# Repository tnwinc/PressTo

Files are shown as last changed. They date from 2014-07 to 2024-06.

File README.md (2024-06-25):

NOTE:
=======
This repo is being archived because it was never used for more than a prototype. The code is obsolete and being retired.

PressTo
=======

Pronounced \'pres-tō\\. This repository contains details on how to make an Adruino powered switch box to select and launch an application. "Press To ..."

# Parts
* Arduino (Uno, Nano, etc., tested with the ATmega328 microcontroller)
* Capacitive Touch Wheel (http://www.dfrobot.com/index.php?route=product/product&product_id=463)
* Green Button (http://amzn.com/B0094GRZPE)
* Red Button (http://amzn.com/B0097A8PK6)
* Plastic Printer (for the housing)

# Hardware
Hopefully a schematic of our design will be provided, but it is not yet available...

## Microcontroller code
Look up the code in ArduinoSide/SelectorDevice/SelectorDevice.ino. The microcontroller code is hooked to A0 (for the Rotary analog input), D2 (green button), D3 (red button), and power (5V) and ground are run as needed to all three components. 

On a button press, the appropriate signal is sent, namely BUTTON_GREEN or BUTTON_RED, but currently a command is only sent on the down press (there is not a separate signal for ON or OFF).

The Rotary switch sends SWITCH_####. The number can be from 0 - 1023, but 1023 means that no connection was made and that value should be screened by the software (it tends to event SWITCH_1023 when switching from one position to another).

# Software
PressTo.sln is the solution, which is located in ComputerSide.

Hardware.csproj contains everything to encapsulate the serial connection and raise events for button clicks and rotary changes.

Switcher.csproj handles the software UI, which listens to signals from the device and responds appropriately. It will hide after the configured timeout (5 seconds) and auto configures the device the first time it is run. Once it is configured, select a position and press the green button to configure an action. An action can launch an executable with parameters (if desired). The Name field shows up when the item is in the Next or Previous switch position state, where as the Description shows up when the item is selected. The image will appear for the Previous, Current, or Next positions of the switch.

# Special Thanks
* The Network - for supplying the hardware and allocating time to the project
* Mit Raval - for suggesting the name
* Tej Gandham - for contributions to the node server and Slack integration

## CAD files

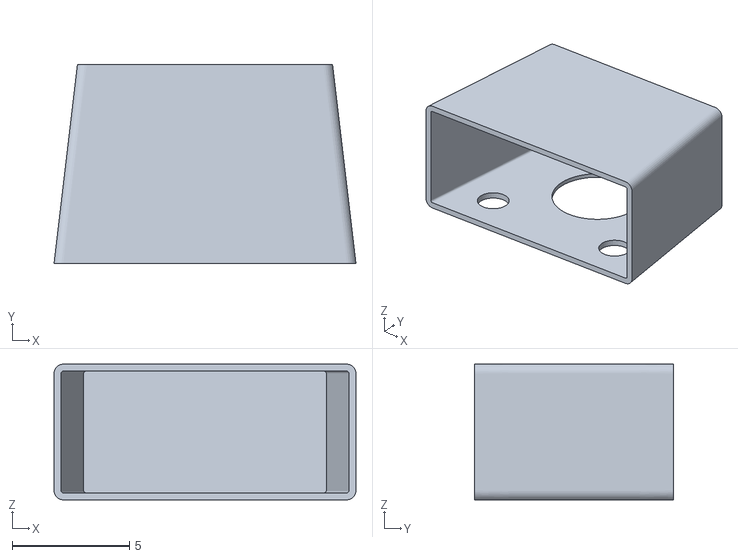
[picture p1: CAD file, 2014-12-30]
Enclosure/Box_mk_IV_config_B.stl
12.9 x 8.50 x 5.80

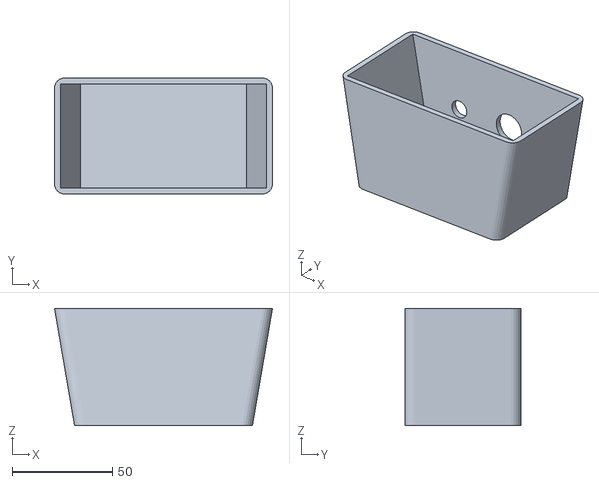
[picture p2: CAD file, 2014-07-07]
Enclosure/Box_mk_III.stl
109.0 x 58.0 x 58.5

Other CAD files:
Enclosure/Box_mk_IV_config_A.stl
Enclosure/Box_mk_II.skp
Enclosure/Box_mk_III.skp
Enclosure/Box_mk_IV_config_A.ipt
Enclosure/Box_mk_IV_config_B.ipt

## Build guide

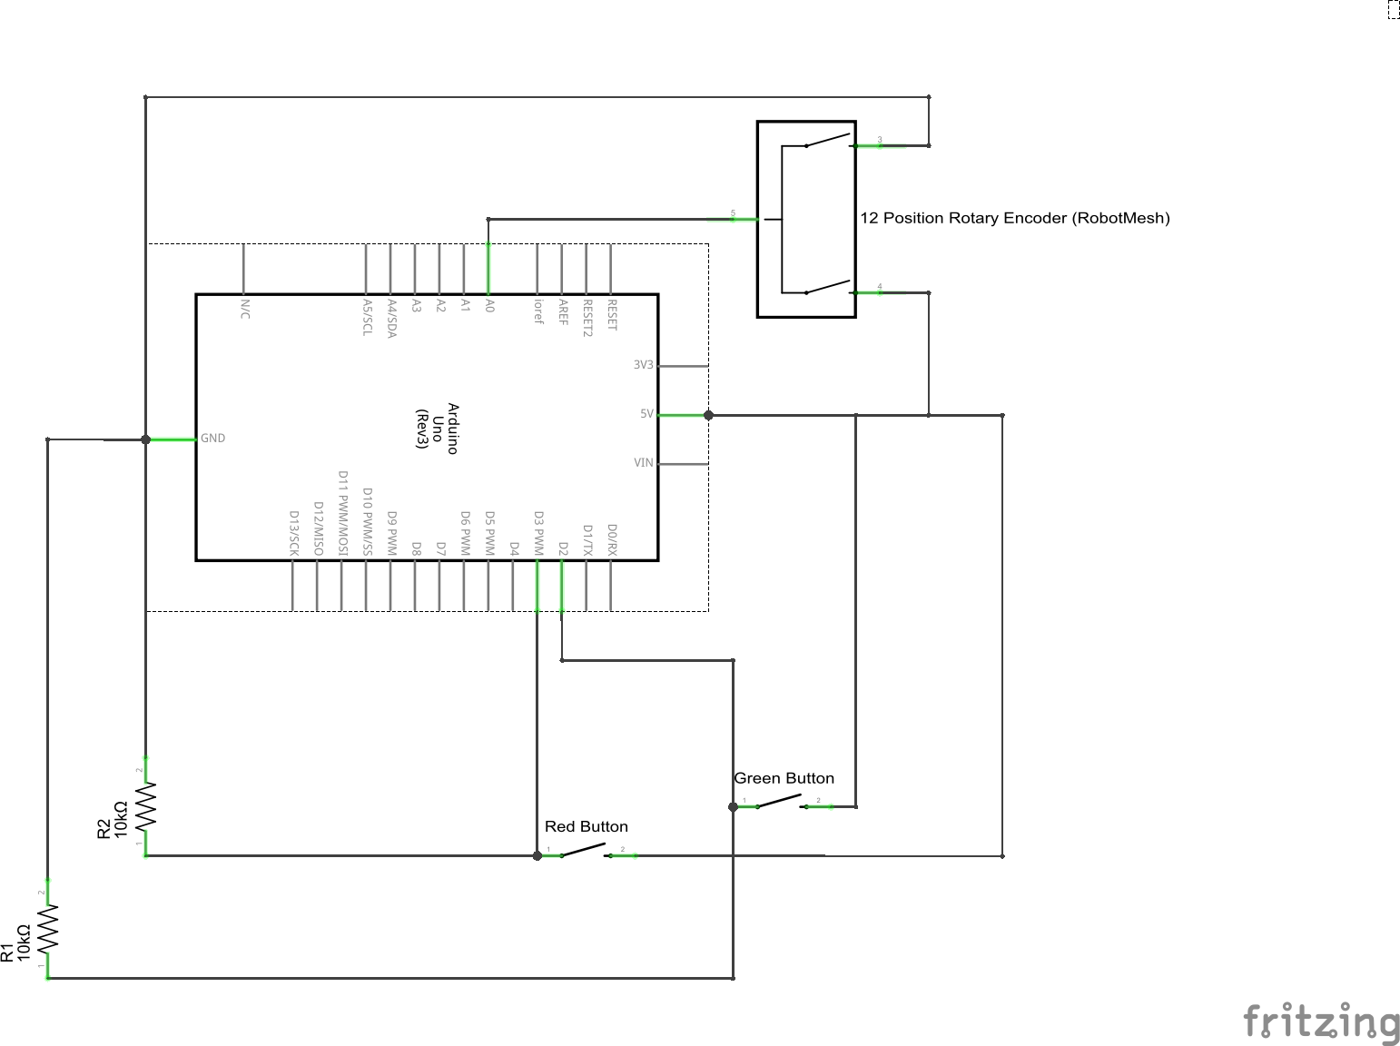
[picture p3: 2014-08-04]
ArduinoSide/PressTo Wiring Diagram.png

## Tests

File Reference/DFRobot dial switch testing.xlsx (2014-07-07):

Position | 1 | 2 | 3 | 4 | 5 | 6 | 7 | 8 | 9 | 10 | 11 | 12
Average | 548.85 | 623.49 | 683.11 | 757.00 | 806.06 | 837.98 | 861.00 | 883.74 | 900.43 | 923.40 | 941.22 | 954.78
Variance | 1 | 1 | 1 | 0 | 1 | 2 | 0 | 1 | 1 | 1 | 1 | 1
Data
 | 548 | 624 | 684 | 757 | 806 | 838 | 861 | 884 | 900 | 923 | 941 | 955
 | 549 | 623 | 683 | 757 | 806 | 838 | 861 | 884 | 900 | 924 | 941 | 955
 | 548 | 623 | 683 | 757 | 806 | 838 | 861 | 884 | 900 | 923 | 941 | 955
 | 549 | 624 | 683 | 757 | 806 | 838 | 861 | 884 | 900 | 923 | 941 | 955
 | 549 | 623 | 683 | 757 | 806 | 838 | 861 | 883 | 900 | 923 | 942 | 954
 | 549 | 624 | 683 | 757 | 806 | 838 | 861 | 883 | 900 | 924 | 941 | 954
 | 549 | 623 | 683 | 757 | 806 | 838 | 861 | 884 | 900 | 924 | 942 | 955
 | 548 | 624 | 683 | 757 | 806 | 838 | 861 | 884 | 901 | 924 | 941 | 955
 | 548 | 623 | 683 | 757 | 806 | 838 | 861 | 884 | 901 | 923 | 942 | 954
 | 549 | 623 | 683 | 757 | 806 | 838 | 861 | 884 | 901 | 924 | 941 | 954
 | 548 | 623 | 683 | 757 | 806 | 838 | 861 | 883 | 900 | 923 | 941 | 955
 | 549 | 623 | 684 | 757 | 806 | 838 | 861 | 884 | 900 | 923 | 941 | 955
 | 549 | 623 | 683 | 757 | 806 | 838 | 861 | 884 | 900 | 923 | 941 | 955
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

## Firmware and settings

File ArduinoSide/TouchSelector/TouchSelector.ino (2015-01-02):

/*
   SDA -> A4
   SCL -> A5
   IRQ -> D2
*/


#include <Wire.h>
#include <mpr121.h>

int key = -1;
int prevKey = -1;
int inc = 0;
long lastTouchTime = 0;
long delayTime = 3000;
long sentWheelIncTime = 0;
long slowInc = 500;

void setup()
{ 
	//  initialize function
  Serial.begin(9600);
  Wire.begin();
  CapaTouch.begin();

  delay(500);
  Serial.println("START"); 
}

void loop()
{
  key=CapaTouch.wheelKey();
  long time = millis();
  long timeDiff = time - lastTouchTime;
  if (key >= 0)
    lastTouchTime = time;
  
  if (prevKey == 20 && key != 20) {
    Serial.println("wheelButton:up");
    prevKey = -1;
  }
  
  if (prevKey != -1 && timeDiff > delayTime)
  {
    prevKey = -1;
    Serial.println("wheel:timeout");
  }
  
  if(key>0 && key<=16){
    if (prevKey > 0)
    {
      inc = (key - prevKey) % 16;
      
      if (inc > 8)
      {
        inc = inc - 16;
      }
      else if (inc < -8)
      {
        inc = inc + 16;
      }
      
      if (inc != 0){
        Serial.print("wheel:");
        if (inc == 2 && time - sentWheelIncTime >= slowInc)
        {
          Serial.println(1);
        }
        else {
          Serial.println(inc);
        }
        sentWheelIncTime = time;
      }
    } else if (prevKey != 20) Serial.println("wheel:touch");
    prevKey = key;
  }
  else if (key == 20 && prevKey != 20){
    Serial.println("wheelButton:down");
    prevKey = key;
  }
  
  delay(100);
}



 

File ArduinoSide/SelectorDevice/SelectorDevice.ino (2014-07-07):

// Pin setup
int btnPinGreen = 2;
int btnPinRed = 3;
int swPinDial = 0;

// State tracking
int value = 0;
int RotaryValue = 0;
int redState = 0;
int greenState = 0;

// Serial input
String command;
String temp1,temp2;
char inByte;
char carray[6]; 

void setup()
{
  Serial.begin(9600);
  
  pinMode(btnPinGreen, INPUT);
  pinMode(btnPinRed, INPUT);
  pinMode(swPinDial, INPUT);
}

void loop()
{
  // Button Input
  value = digitalRead(btnPinGreen);
  if (value != greenState) {
    if (value == HIGH) {
      Serial.println("BUTTON_GREEN");
    }
  }
  greenState = value;
  
  value = digitalRead(btnPinRed);
  if (value != redState) {
    if (value == HIGH) {
      Serial.println("BUTTON_RED");
    }
  }
  redState = value;
  
  // Dial Input
  int swValue = analogRead(swPinDial);
  if (abs(RotaryValue - swValue) > 5) {
    RotaryValue = swValue;
    Serial.print("SWITCH_");
    Serial.println(swValue);
  }
  
  // Query Commands
  if (Serial.available() > 0) {
    inByte = Serial.read();
    
    // upper/lower letters, numbers, underscore
    if ((inByte >= 65 && inByte <= 90) || (inByte >=97 && inByte <=122) || (inByte >= 48 && inByte <=57) || inByte == 95 ) {
      command.concat(inByte);
    }
  }
  
  if (inByte == 10 || inByte == 13) {
    inByte = 0;
  
    if (command.equalsIgnoreCase("get_position")) {
      Serial.print("SWITCH_");
      Serial.println(swValue);
    } else {
      if (!command.equalsIgnoreCase("")) {
        Serial.println("INVALID_REQUEST");
      }
    }
    command = "";
  }
  
  delay(50);  // delay in between reads for stability
}

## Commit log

2014-07-07 Initial commit of all the files...
    [Box_mk_II.skp, Box_mk_III.skp, Box_mk_III.stl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]
2014-08-04 Cleanup unused code and added a wiring diagram.
    [Wiring Diagram.fzz]
2014-12-24 modified enclosure to fit the new hardware, made a new configuration that should look better, given the height of the new enclosure.
    [Box_mk_IV_config_A.ipt, Box_mk_IV_config_A.stl, Box_mk_IV_config_B.ipt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]
2014-12-28 first cut
2014-12-31 WIP - Got communication to the client from Arduino
2015-01-02 Cleanup and added arduino touch library to project.
2015-01-02 Updates to allow up and down action triggers from the touch wheel.
2015-01-02 Minor tweaks for better input stability.
    [TouchSelector.ino, server.js]
2015-01-02 wired to wrong event
